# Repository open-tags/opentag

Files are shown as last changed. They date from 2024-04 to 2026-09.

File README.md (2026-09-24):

# opentag · early UWB prototype

Hardware, firmware, and an iOS app from the early opentags research project.

> **Historical R&D reference.** This prototype predates opentag U1 and uses different hardware and firmware. For current products and setup guides, visit [opentags](https://open-tags.com/) and the [documentation](https://open-tags.com/docs/).

[Hardware](Hardware/) · [Firmware](Firmware/README.md) · [iOS app](iOS/OpenTags/README.md) · [Current ROS 2 source](https://github.com/open-tags/open-tags.github.io/tree/main/ros2)

<p align="center">
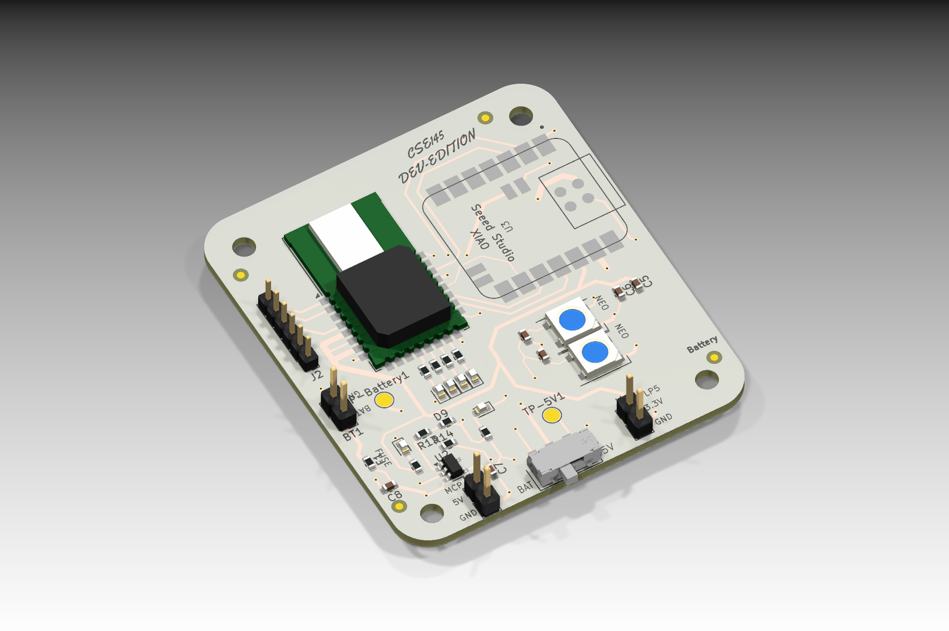
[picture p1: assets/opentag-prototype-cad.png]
KiCad 3D render of the historical opentag circuit board, showing its routing, mounting holes, connectors, and assigned component models
  
  <br>
  <sub>Historical prototype PCB · rendered directly from the KiCad board and its assigned 3D models</sub>
</p>

Some components have no assigned 3D model and appear as bare footprints. [Render details](assets/README.md)

<p align="center">
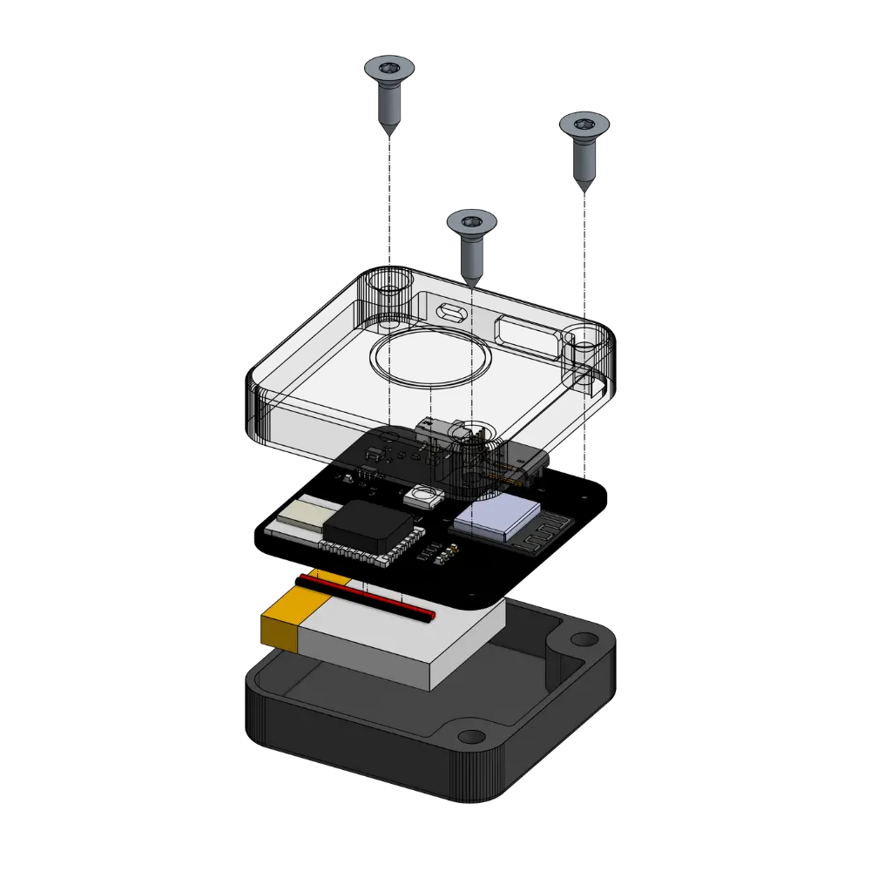
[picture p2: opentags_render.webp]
Original exploded CAD view of the early opentag prototype, showing its enclosure, circuit board, battery, and screws
  
  <br>
  <sub>Original prototype · exploded CAD view</sub>
</p>

## Explore the prototype

The project explored ultra-wideband (UWB) ranging and iPhone interaction. These files preserve that development work; they are not a complete, validated product release.

| Resource | What is included | Start here |
| --- | --- | --- |
| Hardware | KiCad schematics and board layouts, component libraries, BOMs, and fabrication exports | [KiCad project](Hardware/Hardware.kicad_pro) |
| Firmware | Arduino / PlatformIO experiments and bundled radio libraries | [Build notes and missing dependencies](Firmware/README.md) |
| iOS | Xcode project based on Apple's Nearby Interaction accessory sample | [iOS setup notes](iOS/OpenTags/README.md) |

## Before building

- **Firmware dependencies are incomplete.** The active PlatformIO target is `xiaoble_adafruit_nrf52`. The source includes `niq.h` and the configuration references NIQ libraries that are not included in this repository. A clean checkout is not ready to build; see the [firmware notes](Firmware/README.md).
- **The iOS app is experimental.** Its setup notes require an iPhone with Apple's U1 chip and a compatible accessory. Apple's U1 chip is unrelated to the opentag U1 product name.
- **Hardware files record prototype revisions.** Check the schematic, board revision, and firmware pin assignments together before fabrication or flashing.

## Current opentags resources

opentags now builds tracking hardware and integration tools for robotics. Start with the [website](https://open-tags.com/) for current products, the [documentation](https://open-tags.com/docs/) for setup, or the [ROS 2 source](https://github.com/open-tags/open-tags.github.io/tree/main/ros2) for robot integration.

This repository's prototype files and license do not describe the hardware, firmware, or licensing of current products.

## Questions and corrections

Use [Issues](https://github.com/open-tags/opentag/issues) for questions or corrections about this prototype. Include the board revision, toolchain, and relevant logs when reporting a build problem. For current product inquiries, contact [hello@open-tags.com](mailto:hello@open-tags.com).

## License

See the repository's [MIT license](LICENSE). Bundled third-party components retain their own license notices, including the [iOS sample](iOS/OpenTags/LICENSE/LICENSE.txt) and [Adafruit nRFCrypto](Firmware/lib/Adafruit_nRFCrypto/LICENSE).

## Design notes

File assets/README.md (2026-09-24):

# README render

`opentag-prototype-cad.png` was ray-traced with KiCad CLI 10.0.1 from
[`Hardware/Hardware.kicad_pcb`](../Hardware/Hardware.kicad_pcb). No generative AI
was used for this image.

The render preserves the board geometry, copper, silkscreen, component placements,
and assigned model transforms. Model paths were resolved in a temporary copy:
`${KIPRJMOD}` points to the original Hardware directory, and legacy KiCad 8 `.wrl`
references use the same-named `.step` models in the installed KiCad 10 library.
The source board and schematic were not modified.

Render settings: 1800 × 1200 pixels, top view, rotation `325,0,30`, zoom `0.72`,
high quality, opaque background, and floor shadows; board stackup colors retained.

This is a visualization of the saved CAD state, not a complete assembly model.
The Seeed Studio XIAO footprint has no assigned model. The radio footprint uses
the board's existing DWM1000 model assignment, despite its DWM3000 electrical
labels. These historical modeling limitations are preserved rather than filled
in with invented geometry.

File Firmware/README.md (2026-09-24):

# Prototype firmware

Arduino / PlatformIO experiments for the early opentag hardware. For current opentag U1 setup, use the [current documentation](https://open-tags.com/docs/).

## Build status

**A clean checkout is missing dependencies required by the firmware.**

The active environment in [platformio.ini](platformio.ini) is `xiaoble_adafruit_nrf52`, using the `xiaoble_adafruit` board and a custom Nordic nRF52 platform. The older `esp32-c3-devkitm-1` configuration is commented out and is not an active build target.

The checkout has these known dependency gaps:

- [src/main.cpp](src/main.cpp) includes `niq.h`, but that header is not present.
- The configuration searches `lib/niq/Inc` and links `niq-m4-hfp-1.1.0.0` and `niq-m4-sfp-1.1.0.0`. Those NIQ files are not tracked; `lib/niq` is excluded by the existing [.gitignore](.gitignore).
- Several configured include paths under `src/Comm`, `src/Helpers`, `src/AppConfig`, and `src/fira`, plus `lib/HAL/Inc`, are also absent.

Recover the matching dependencies and confirm their license terms before attempting a build. The custom platform URL is not pinned to a revision, so the configuration also does not capture a reproducible historical toolchain. Resolving the missing files alone does not establish a working build.

## Build after restoring dependencies

Install [PlatformIO Core](https://docs.platformio.org/page/core.html), then run from this repository's root:

```sh
cd Firmware
pio run -e xiaoble_adafruit_nrf52
```

This command selects the environment currently defined in the project; it is not a verified successful build. Confirm the board revision and pin assignments before uploading firmware to hardware.

To remove local build output:

```sh
pio run --target clean
```

[Back to the prototype overview](../README.md)

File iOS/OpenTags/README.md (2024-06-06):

# Implementing Spatial Interactions with Third-Party Accessories

Establish a connection with a nearby accessory to receive periodic measurements of its distance from the user.

## Overview

- Note: This sample code project is associated with WWDC21 session [10165: Explore Nearby Interaction with Third-Party Accessories](https://developer.apple.com/wwdc21/10165).

## Configure the Sample Code Project

Set the run destination to an iPhone that contains a U1 chip. The sample app interacts with an accessory you partner with or develop using the [Ultra Wideband (UWB) third-party device specification](https://developer.apple.com/nearby-interaction).

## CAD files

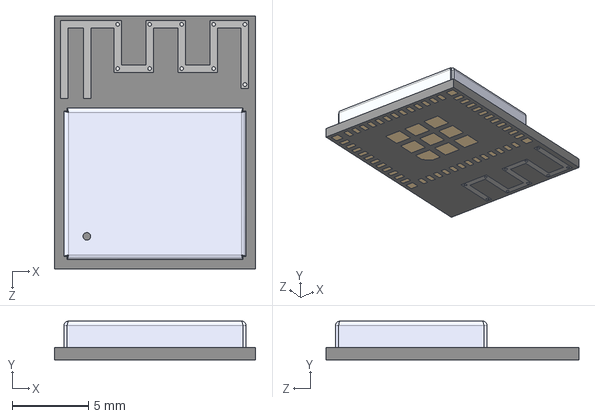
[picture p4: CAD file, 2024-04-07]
Hardware/ESP32-C3-MINI-1-N4/ESP32-C3-MINI-1-N4.step
13.2 x 2.55 x 16.6 mm

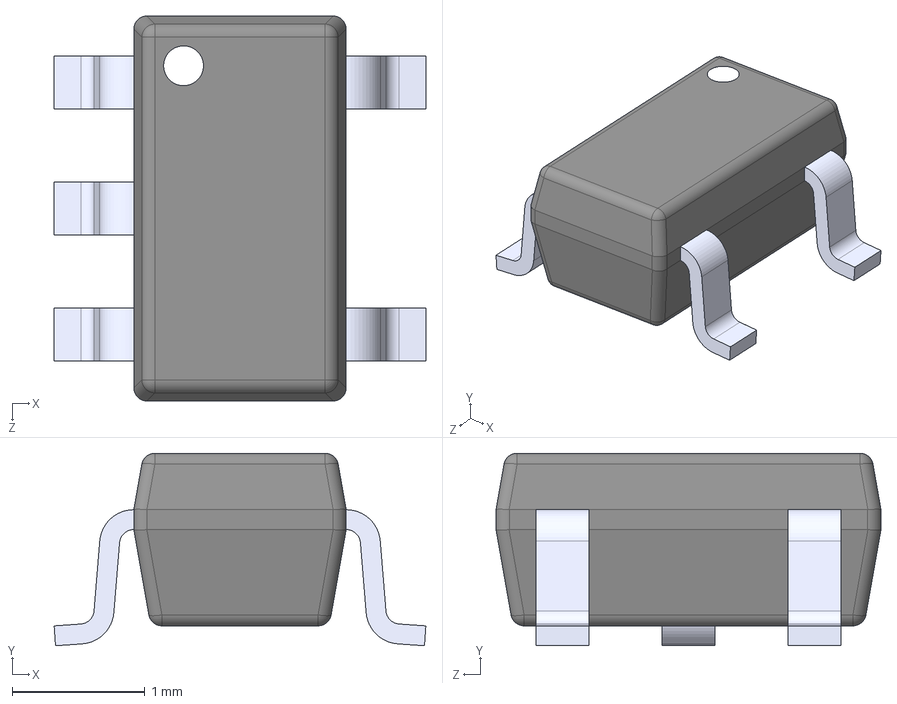
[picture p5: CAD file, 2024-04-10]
Hardware/LP5907MFX-3.3_NOPB/LP5907MFX-3.3_NOPB.step
2.80 x 1.45 x 2.90 mm

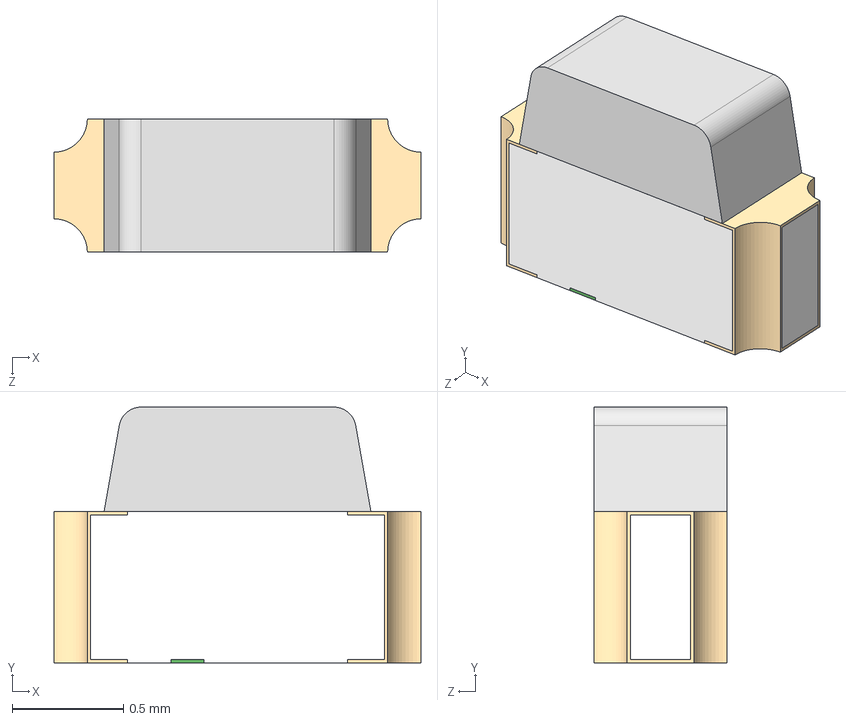
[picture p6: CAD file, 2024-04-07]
Hardware/LTST-S270KRKT/LTST-S270KRKT.step
1.65 x 1.15 x 0.6 mm

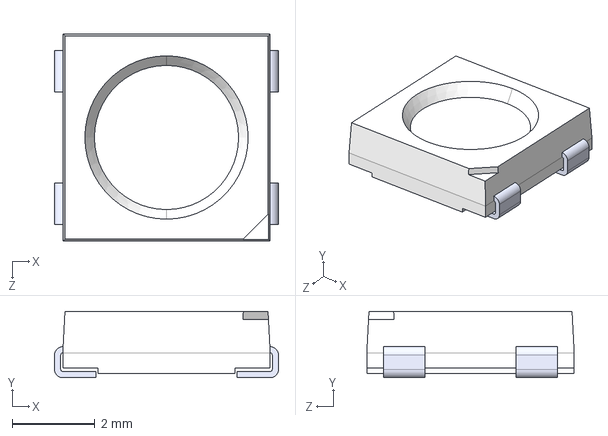
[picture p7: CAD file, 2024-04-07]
Hardware/NeoPixel/1655--3DModel-STEP-56544.STEP
5.40 x 1.60 x 5.00 mm

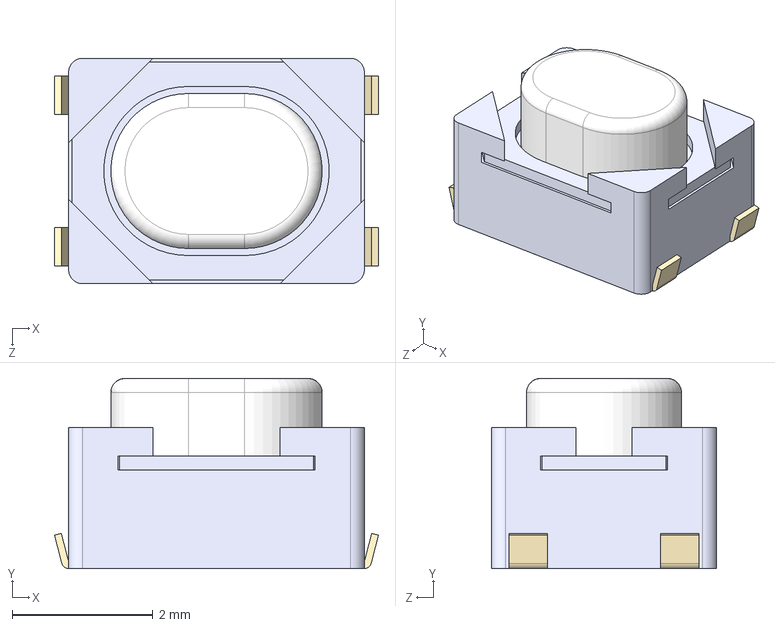
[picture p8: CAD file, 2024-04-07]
Hardware/PTS810 SJK 250 SMTR LFS--3DModel-STEP-56544.STEP
4.60 x 2.70 x 3.20 mm

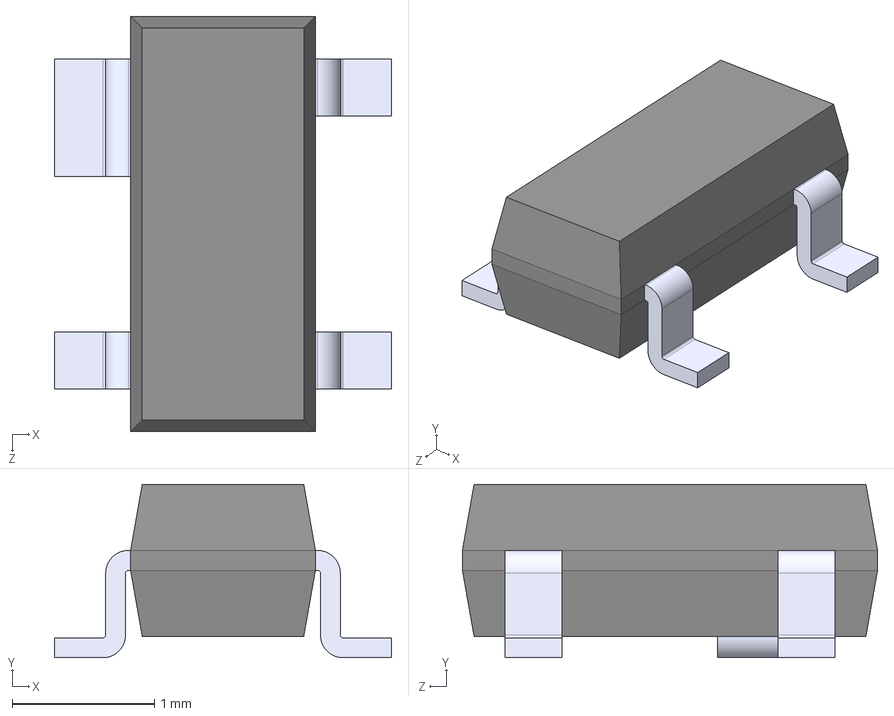
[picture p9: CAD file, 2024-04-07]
Hardware/SP0503BAHTG/SP0503BAHTG.step
2.37 x 1.22 x 2.92 mm

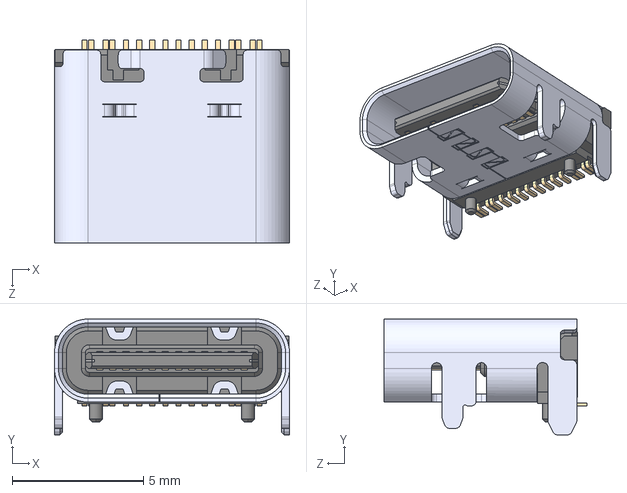
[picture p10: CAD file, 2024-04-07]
Hardware/USB4105-GF-A/USB4105-GF-A.step
8.94 x 4.41 x 7.71 mm

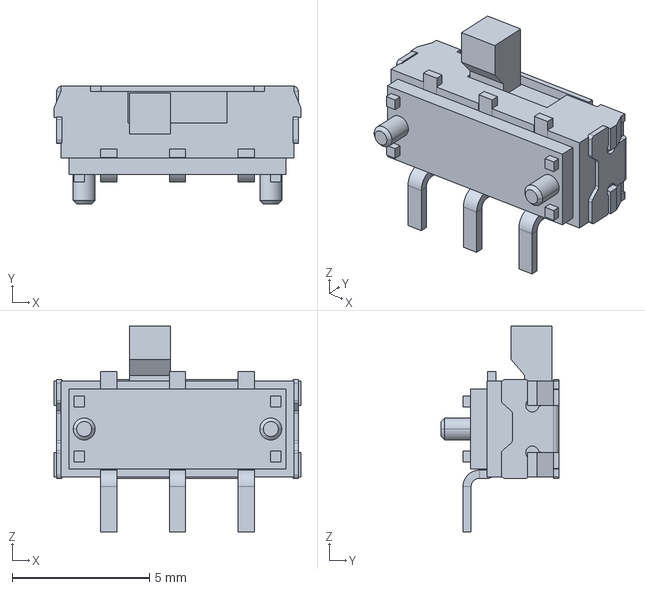
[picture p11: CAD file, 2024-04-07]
Hardware/JS102011SAQN/JS102011SAQN.step
9.00 x 4.30 x 7.50 mm

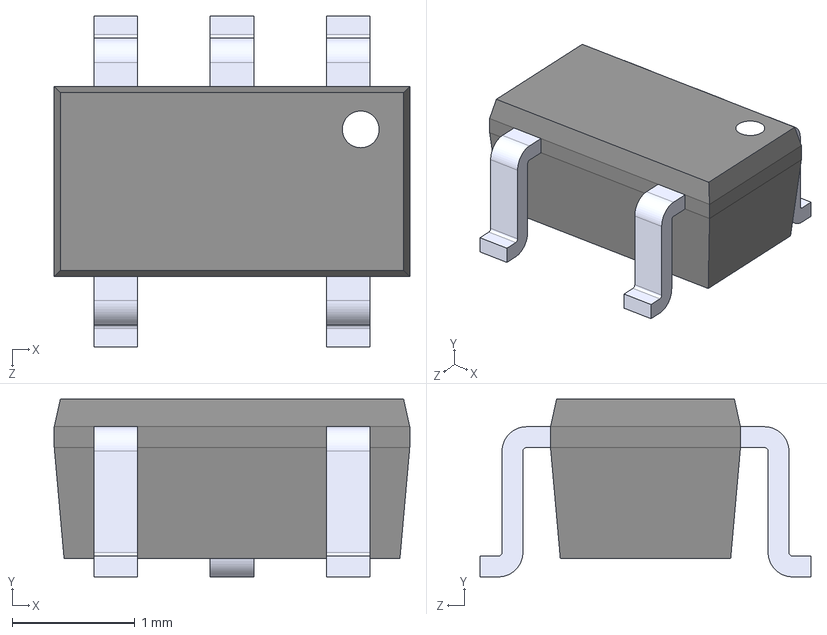
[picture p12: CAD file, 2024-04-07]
Hardware/MCP73831T-5ACI_OT/MCP73831T-5ACI_OT.step
2.90 x 1.45 x 2.70 mm

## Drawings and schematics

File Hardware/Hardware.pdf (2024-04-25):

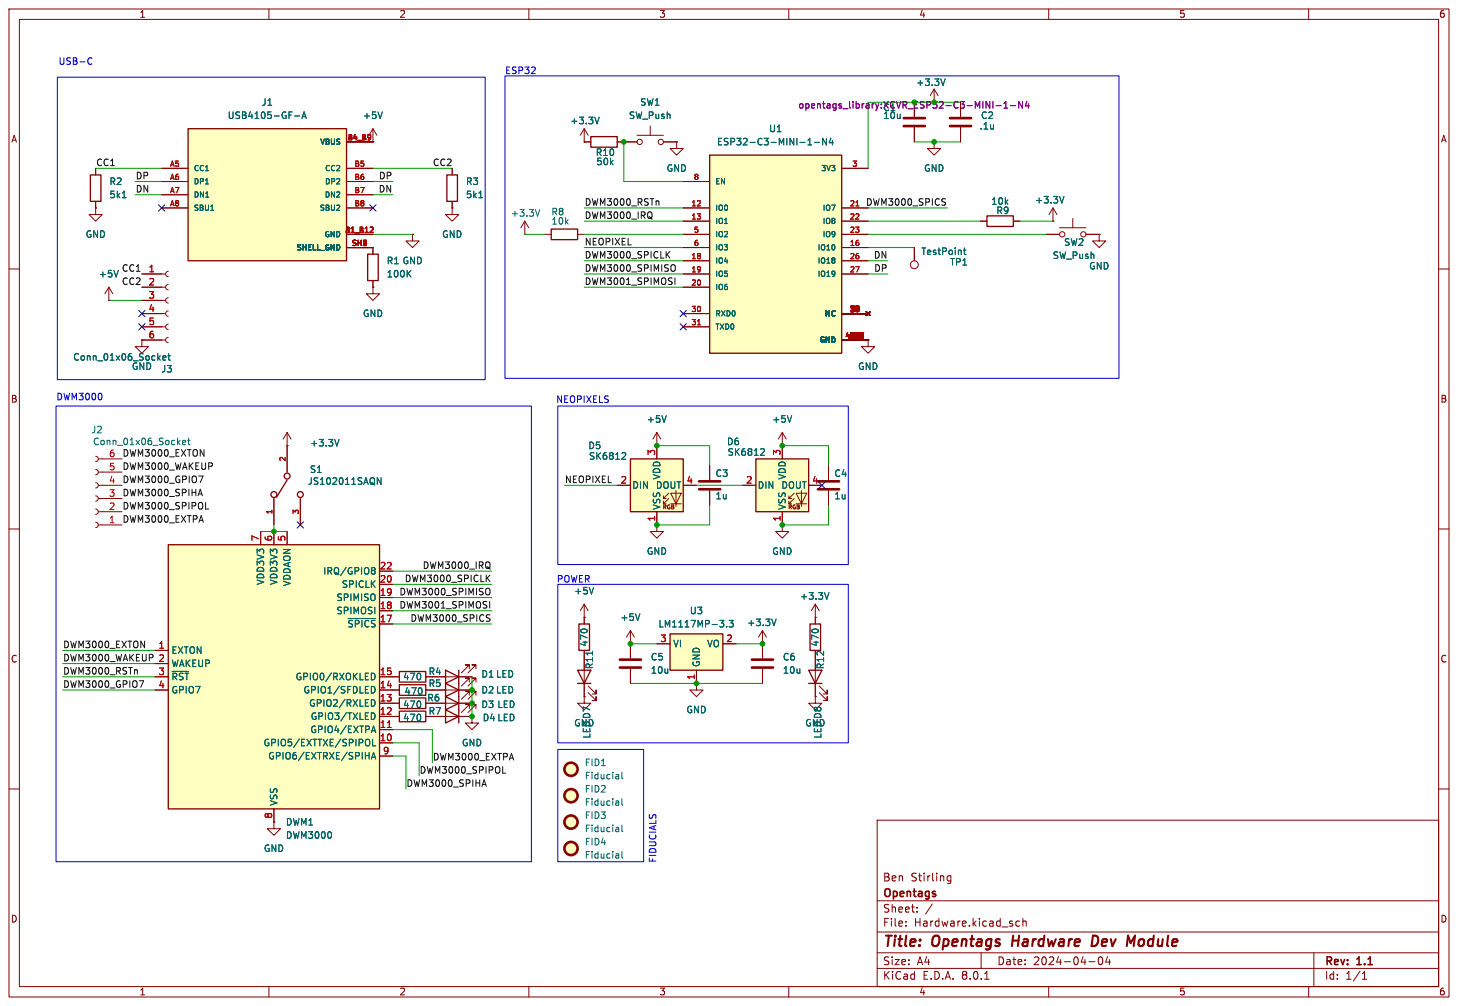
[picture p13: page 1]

File: Hardware.kicad_sch Sheet: / Opentags Ben Stirling

Id: 1/1 Title: Opentags Hardware Dev Module

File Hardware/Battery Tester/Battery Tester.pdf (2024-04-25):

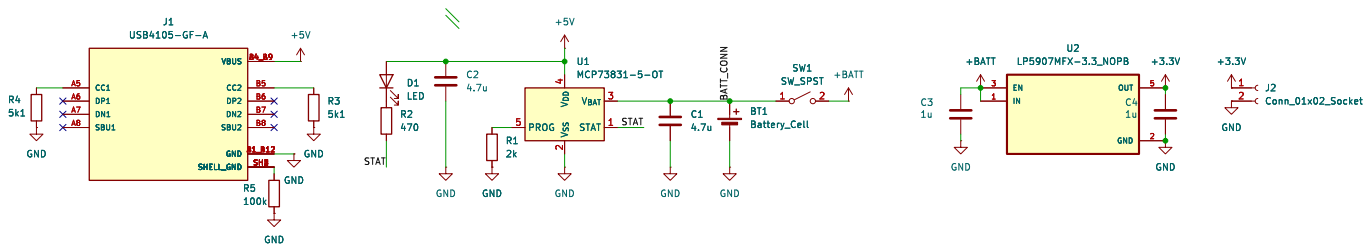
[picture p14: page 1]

Id: 1/1 Title: Battery Tester File: Battery Tester.kicad_sch Sheet: /

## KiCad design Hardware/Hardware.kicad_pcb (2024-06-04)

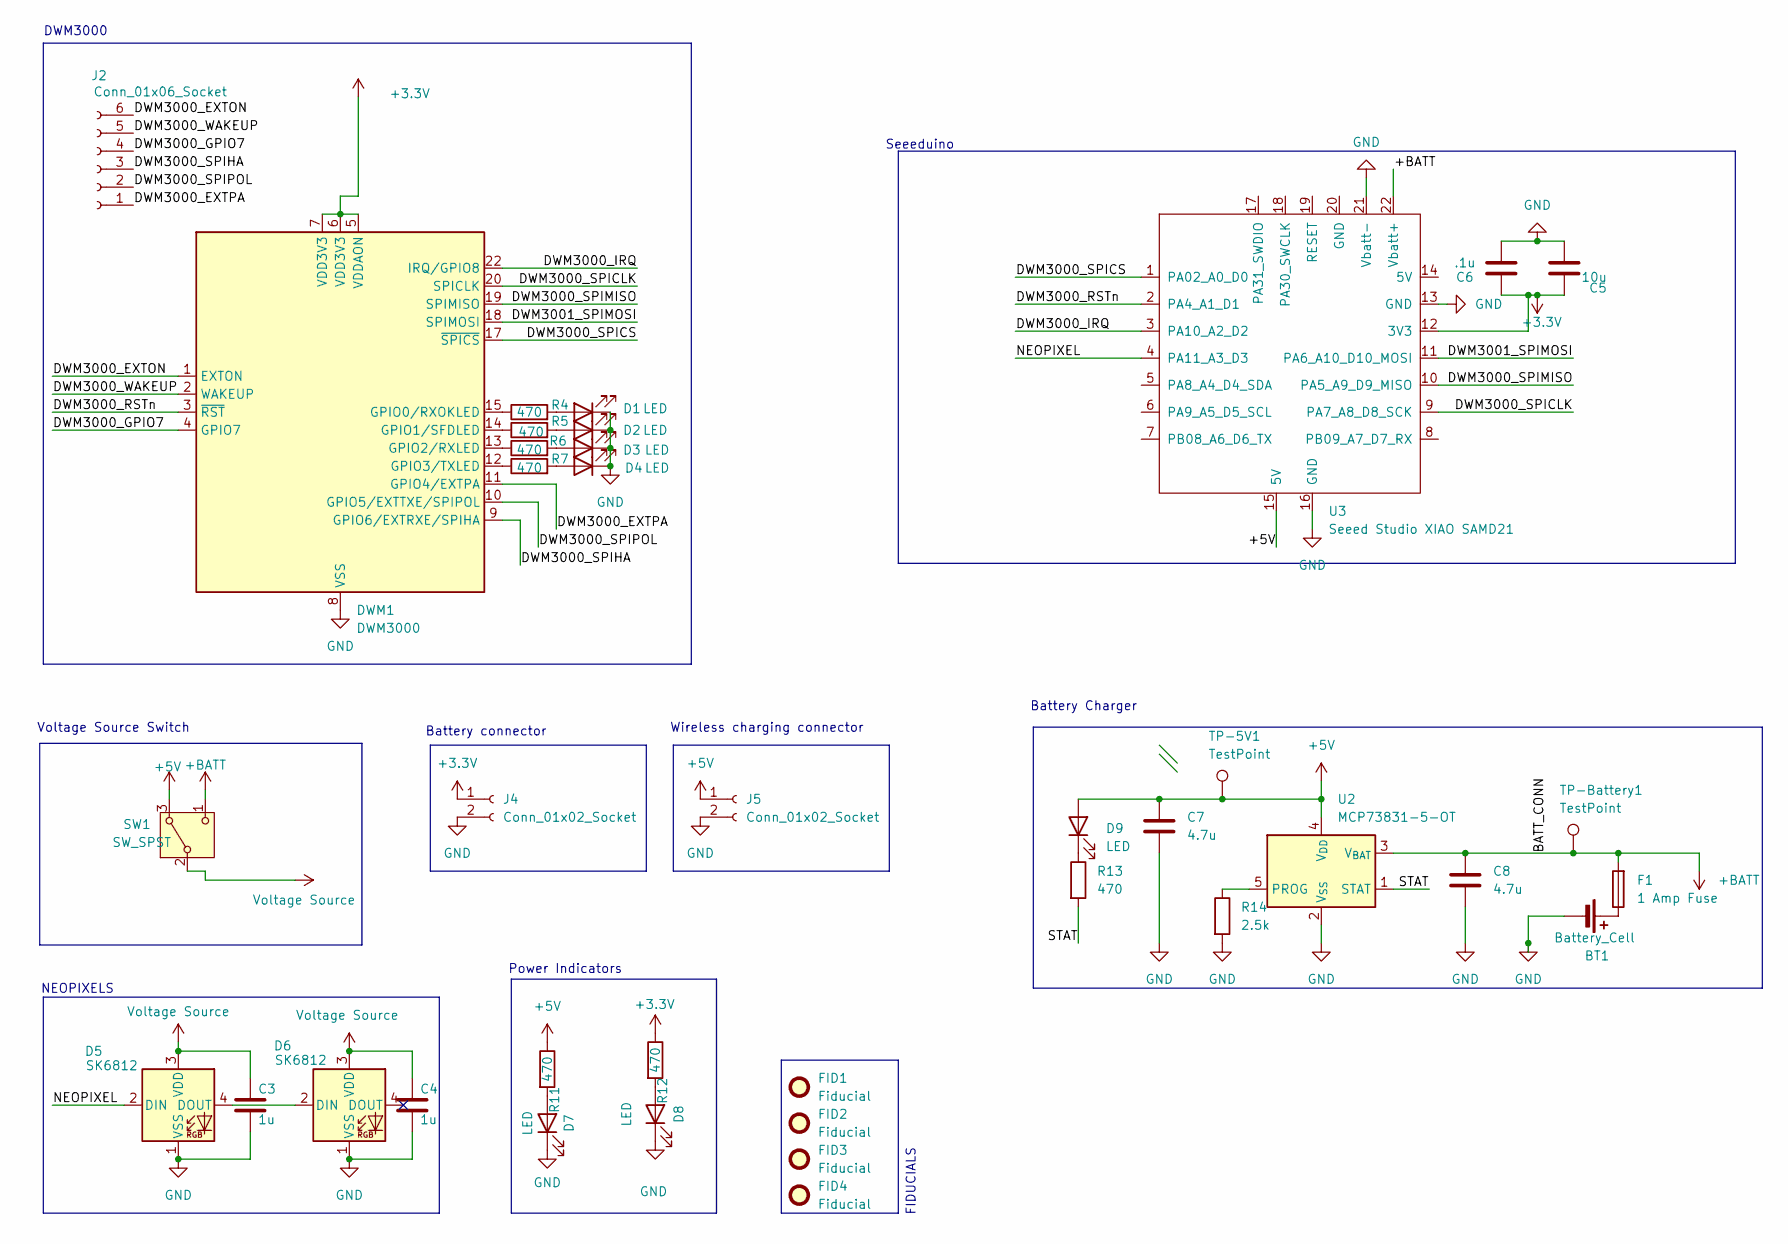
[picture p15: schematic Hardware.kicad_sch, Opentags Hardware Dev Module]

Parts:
BT1: Battery_Cell; PinHeader_1x02_P2.54mm_Vertical
C3, C4: 1u; C_0603_1608Metric
C5: 10u; C_0603_1608Metric
C6: .1u; C_0603_1608Metric
C7, C8: 4.7u; C_0603_1608Metric
D1, D2, D3, D4, D7, D8: LED; LED_0603_1608Metric
D5, D6: SK6812; LED_SK6812_PLCC4_5.0x5.0mm_P3.2mm
D9: LED; R_0603_1608Metric
DWM1: DWM3000; DWM1000
F1: 1 Amp Fuse; Fuse_0603_1608Metric
FID1, FID2, FID3, FID4: Fiducial; Fiducial_1mm_Mask2mm
J2: Conn_01x06_Socket; PinHeader_1x06_P2.00mm_Vertical
J4, J5: Conn_01x02_Socket; PinHeader_1x02_P2.54mm_Vertical
R4, R5, R6, R7, R11, R12, R13: 470; R_0603_1608Metric
R14: 2.5k; R_0603_1608Metric
SW1: SW_SPST; SW_JS102011SAQN
TP-5V1: TestPoint; TestPoint_Pad_D2.0mm
TP-Battery1: TestPoint; TestPoint_Pad_D2.0mm
U2: MCP73831-5-OT; SOT-23-5
U3: Seeed Studio XIAO SAMD21; XIAO-nRF52840-Sense-14P-2.54-21X17.8MM

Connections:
+3.3V: C5.1, C6.1, DWM1.5 (VDDAON), DWM1.6 (VDD3V3), DWM1.7 (VDD3V3), J4.1, R12.1, U3.12 (3V3)
+5V: C7.1, D9.2 (A), J5.1, R11.1, SW1.3 (A), TP-5V1.1, U2.4 (V_{DD}), U3.15 (5V)
+BATT: C8.1, F1.2, SW1.1 (C), TP-Battery1.1, U2.3 (V_{BAT}), U3.22 (Vbatt+)
/DWM3000_EXTON: DWM1.1 (EXTON), J2.6
/DWM3000_EXTPA: DWM1.11 (GPIO4/EXTPA), J2.1
/DWM3000_GPIO7: DWM1.4 (GPIO7), J2.4
/DWM3000_IRQ: DWM1.22 (IRQ/GPIO8), U3.3 (PA10_A2_D2)
/DWM3000_RSTn: DWM1.3 (~RST), U3.2 (PA4_A1_D1)
/DWM3000_SPICLK: DWM1.20 (SPICLK), U3.9 (PA7_A8_D8_SCK)
/DWM3000_SPICS: DWM1.17 (~SPICS), U3.1 (PA02_A0_D0)
/DWM3000_SPIHA: DWM1.9 (GPIO6/EXTRXE/SPIHA), J2.3
/DWM3000_SPIMISO: DWM1.19 (SPIMISO), U3.10 (PA5_A9_D9_MISO)
/DWM3000_SPIPOL: DWM1.10 (GPIO5/EXTTXE/SPIPOL), J2.2
/DWM3000_WAKEUP: DWM1.2 (WAKEUP), J2.5
/DWM3001_SPIMOSI: DWM1.18 (SPIMOSI), U3.11 (PA6_A10_D10_MOSI)
/NEOPIXEL: D5.2 (DIN), U3.4 (PA11_A3_D3)
/STAT: R13.2, U2.1 (STAT)
GND: BT1.2 (-), C3.1, C4.1, C5.2, C6.2, C7.2, C8.2, D1.1 (K), D2.1 (K), D3.1 (K), D4.1 (K), D5.1 (VSS), D6.1 (VSS), D7.1 (K), D8.1 (K), DWM1.8 (VSS), DWM1.16 (VSS), DWM1.21 (VSS), DWM1.23 (VSS), DWM1.24 (VSS), J4.2, J5.2, R14.2, U2.2 (V_{SS}), U3.13 (GND), U3.16 (GND), U3.21 (Vbatt-)
unnamed: BT1.1 (+), F1.1
unnamed: D1.2 (A), R4.2
unnamed: D2.2 (A), R5.2
unnamed: D3.2 (A), R6.2
unnamed: D4.2 (A), R7.2
unnamed: D5.4 (DOUT), D6.2 (DIN)
unnamed: D7.2 (A), R11.2
unnamed: D8.2 (A), R12.2
unnamed: D9.1 (K), R13.1
unnamed: DWM1.15 (GPIO0/RXOKLED), R4.1
unnamed: DWM1.14 (GPIO1/SFDLED), R5.1
unnamed: DWM1.13 (GPIO2/RXLED), R6.1
unnamed: DWM1.12 (GPIO3/TXLED), R7.1
unnamed: R14.1, U2.5 (PROG)
Voltage Source: C3.2, C4.2, D5.3 (VDD), D6.3 (VDD), SW1.2 (B)

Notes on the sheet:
Seeeduino
DWM3000
FIDUCIALS
Wireless charging connector
Battery Charger
NEOPIXELS
Power Indicators
Battery connector
Voltage Source Switch

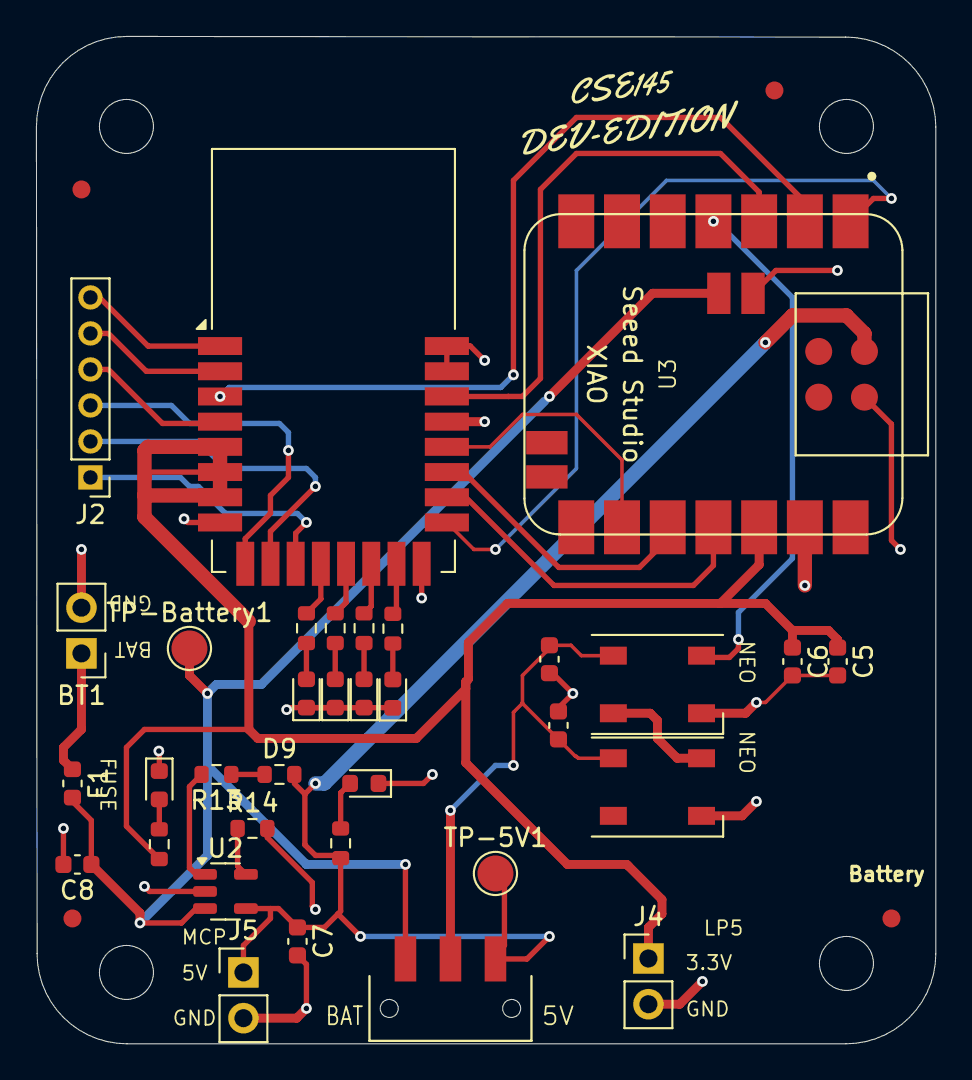
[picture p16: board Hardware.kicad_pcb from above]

Board: 2 copper layers, 50.0 x 56.0 mm, 38 parts (0 on the bottom side), 33 nets.

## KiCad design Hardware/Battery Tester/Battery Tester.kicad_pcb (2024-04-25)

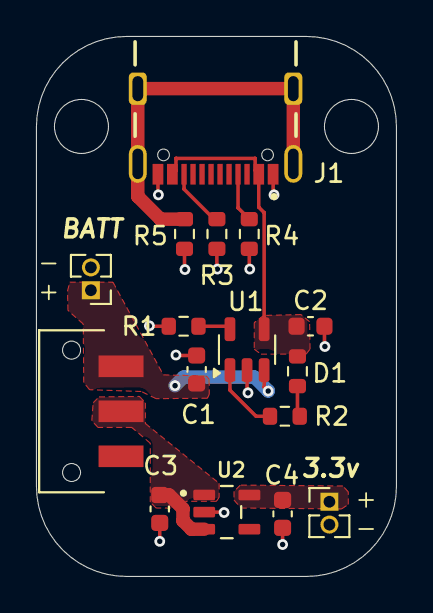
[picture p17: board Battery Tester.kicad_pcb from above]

Board: 2 copper layers, 20.0 x 30.0 mm, 16 parts (0 on the bottom side), 11 nets.

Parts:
3.3v: Conn_01x02_Socket; PinHeader_1x02_P1.27mm_Vertical
BATT: Battery_Cell; PinHeader_1x02_P1.27mm_Vertical
C1, C2: 4.7u; C_0603_1608Metric
C3, C4: 1u; C_0603_1608Metric
D1: LED; R_0603_1608Metric
J1: USB4105-GF-A; GCT_USB4105-GF-A
R1: 2k; R_0603_1608Metric
R2: 470; R_0603_1608Metric
R3, R4: 5k1; R_0603_1608Metric
R5: 100k; R_0603_1608Metric
SW1: SW_SPST; SW_JS102011SAQN
U1: MCP73831-5-OT; SOT-23-5
U2: LP5907MFX-3.3_NOPB; SOT95P280X145-5N

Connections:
+3.3V: 3.3v.1, C4.1, U2.5 (OUT)
+5V: C2.1, D1.2 (A), J1.A4_B9 (VBUS), J1.B4_A9 (VBUS), U1.4 (V_{DD})
+BATT: C3.1, SW1.2 (B), U2.1 (IN), U2.3 (EN)
/BATT_CONN: BATT.1 (+), C1.1, SW1.1 (A), U1.3 (V_{BAT})
/STAT: R2.2, U1.1 (STAT)
GND: 3.3v.2, BATT.2 (-), C1.2, C2.2, C3.2, C4.2, J1.A1_B12 (GND), J1.B1_A12 (GND), R1.2, R3.2, R4.2, R5.2, U1.2 (V_{SS}), U2.2 (GND)
unnamed: D1.1 (K), R2.1
unnamed: J1.A5 (CC1), R4.1
unnamed: J1.B5 (CC2), R3.1
unnamed: J1.SH1 (SHELL_GND), J1.SH2 (SHELL_GND), J1.SH3 (SHELL_GND), J1.SH4 (SHELL_GND), R5.1
unnamed: R1.1, U1.5 (PROG)

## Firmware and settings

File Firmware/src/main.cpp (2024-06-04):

#include "Arduino.h"
#include <stdio.h>
#include <dw3000.h>
extern "C" {
  #include <niq.h>
}

#include "Adafruit_nRFCrypto.h"
#include <BLEService.h>
#include <BLECharacteristic.h>
#include <bluefruit.h>


// Definitions 
#define APP_NAME "OPENTAG"
#define SPI_MOSI 10
#define SPI_MISO 9
#define SPI_SCK 8
#define SPI_CS 0
#define RST 1
#define IRQ 2

// BLE Service
BLEService myService("26b886e0-0bab-4d96-a8f3-f44fe442a700");
BLEService ANIService("48fe3e40-0817-4bb2-8633-3073689c2dba");

// BLE Characteristics
BLECharacteristic myTxChar("6E400002-B5A3-F393-E0A9-E50E24DCCA9E", BLEWrite | BLENotify | BLEIndicate, 38, true);
BLECharacteristic myRxChar("6E400003-B5A3-F393-E0A9-E50E24DCCA9E", BLERead);
BLECharacteristic ACD("95e8d9d5-d8ef-4721-9a4e-807375f53328", BLERead);

#define TX_ANT_DLY 16385
#define RX_ANT_DLY 16385

// DWM-3000 SPI commands
#define DWM3000_DEVID_REG 0x00

/* Frames used in the ranging process. See NOTE 3 below. */
static uint8_t tx_poll_msg[] = {0x41, 0x88, 0, 0xCA, 0xDE, 'W', 'A', 'V', 'E', 0xE0, 0, 0};
static uint8_t rx_resp_msg[] = {0x41, 0x88, 0, 0xCA, 0xDE, 'V', 'E', 'W', 'A', 0xE1, 0, 0, 0, 0, 0, 0, 0, 0, 0, 0};
/* Length of the common part of the message (up to and including the function code, see NOTE 3 below). */
#define ALL_MSG_COMMON_LEN 10
/* Indexes to access some of the fields in the frames defined above. */
#define ALL_MSG_SN_IDX 2
#define RESP_MSG_POLL_RX_TS_IDX 10
#define RESP_MSG_RESP_TX_TS_IDX 14
#define RESP_MSG_TS_LEN 4
/* Frame sequence number, incremented after each transmission. */
static uint8_t frame_seq_nb = 0;

/* Buffer to store received response message.
 * Its size is adjusted to longest frame that this example code is supposed to handle. */
#define RX_BUF_LEN 20
static uint8_t rx_buffer[RX_BUF_LEN];

/* Hold copy of status register state here for reference so that it can be examined at a debug breakpoint. */
static uint32_t status_reg = 0;
volatile static uint8_t start_uwb = 0;

/* Delay between frames, in UWB microseconds. See NOTE 1 below. */
#ifdef RPI_BUILD
#define POLL_TX_TO_RESP_RX_DLY_UUS 240
#endif //RPI_BUILD
#ifdef STM32F429xx
#define POLL_TX_TO_RESP_RX_DLY_UUS 240
#endif //STM32F429xx
#ifdef NRF52840_XXAA
#define POLL_TX_TO_RESP_RX_DLY_UUS 240
#endif //NRF52840_XXAA
/* Receive response timeout. See NOTE 5 below. */
#ifdef RPI_BUILD
#define RESP_RX_TIMEOUT_UUS 270
#endif //RPI_BUILD
#ifdef STM32F429xx
#define RESP_RX_TIMEOUT_UUS 210
#endif //STM32F429xx
#ifdef NRF52840_XXAA
#define RESP_RX_TIMEOUT_UUS 100
#endif //NRF52840_XXAA

#define POLL_TX_TO_RESP_RX_DLY_UUS 240
#define RESP_RX_TIMEOUT_UUS 0

dwt_config_t * dwt_config;

/* Hold copies of computed time of flight and distance here for reference so that it can be examined at a debug breakpoint. */
static double tof;
static double distance;

static uint8_t accessory_config_data_buffer[sizeof(struct AccessoryConfigurationData)];
static uint8_t accessory_config_data_length;

fira_device_configure_t fira_config;
extern dwt_txconfig_t txconfig_options;

static void send_accessory_config_data();

//**************************************************************************************************************
// BLE Related Methods
//*******************************************************************************************************

/**
 * Method to notify the client from the peripheral
*/
static void send_ble_data(uint8_t * buffer, uint16_t data_len){
  bool success = myTxChar.notify(buffer, data_len);
  if (success) {
    Serial.println("Data sent successfully");
  } else {
    Serial.println("Failed to send data");
  }
}

/**
 * Connect Callback for BLE
*/
static void send_ack_uwb_started(void)
{
      // Send "UWB did start" BLE message to the app
      uint8_t buffer[1] = {2};
      send_ble_data(buffer, 1);
}

void connect_callback(uint16_t conn_handle)
{
  Serial.print("【connect_callback】 conn_Handle : ");
  Serial.println(conn_handle, HEX);

  // Get the reference to current connection
  BLEConnection* connection = Bluefruit.Connection(conn_handle);

  Serial.println();
  // request PHY changed to 2MB (2Mbit/sec moduration) 1 --> 2
  Serial.print("Request to change PHY : "); Serial.print(connection->getPHY());
  connection->requestPHY();
  delayMicroseconds(1000000);  // delay a bit for all the request to complete
  Serial.print(" --> "); Serial.println(connection->getPHY());

  // request to update data length  27 --> 251
  Serial.print("Request to change Data Length : "); Serial.print(connection->getDataLength());
  connection->requestDataLengthUpdate();
  delayMicroseconds(1000000);  // delay a bit for all the request to complete
  Serial.print(" --> "); Serial.println(connection->getDataLength());
    
  // request mtu exchange 23 --> 247
  Serial.print("Request to change MTU : "); Serial.print(connection->getMtu());
  connection->requestMtuExchange(247);  // max 247
  //  connection->requestMtuExchange(123);  // max 247
  delayMicroseconds(1000000);  // delay a bit for all the request to complete
  Serial.print(" --> "); Serial.println(connection->getMtu());

  // request connection interval  16(20mS) --> 16(20mS)
  Serial.print("Request to change Interval : "); Serial.print(connection->getConnectionInterval());
  //  connection->requestConnectionParameter(16); // 20mS(in unit of 1.25) default 20mS
  delayMicroseconds(1000000);  // delay a bit for all the request to complete
  Serial.print(" --> "); Serial.println(connection->getConnectionInterval());

  char central_name[32] = { 0 };
  connection->getPeerName(central_name, sizeof(central_name));

  Serial.print("【connect_callback】 Connected to ");
  Serial.println(central_name);
}

/**
 * Disconnect Callback for BLE
*/
void disconnect_callback(uint16_t conn_handle, uint8_t reason)
{
  (void) conn_handle;
  (void) reason;

  Serial.print("【disconnect_callback】 reason = 0x");
  Serial.println(reason, HEX);
}

/**
 * Method to send the iPhone acknowledgement of 
 * receiving of Shared Configuration data
*/
static void send_ack_uwb_stopped(void)
{
    uint8_t buffer[1];
    ni_packet_t * packet = (ni_packet_t *)buffer;
    packet->message_id = (uint8_t)MessageId_accessoryUwbDidStop;
    send_ble_data(buffer, 1);
}

/**
 * This is the callback method passed onto the TX Characteristic 
*/
void onDataWritten(uint16_t conn_hdl, BLECharacteristic* chr, uint8_t* data, uint16_t len) {
  ni_packet_t * packet = (ni_packet_t *)data;
  switch (packet->message_id) {
    case MessageId_init: {
      send_accessory_config_data();
      break;
    }
    case MessageId_configure_and_start: {
      int ret;
      ret = niq_configure_and_start_uwb(packet->payload, len-1, (void*)&fira_config);

      switch(ret)
      {
      case -E_NIQ_INPVAL:
            Serial.println("ERROR: Data len wrong");
            break;
      case -E_NIQ_VERSIONNOTSUPPORTED:
            Serial.println("ERROR: Protocol version not supported");
            break;
      default:
        //Serial.println("UWB STARTED");
        send_ack_uwb_started();
        Serial.println("TWR Started");
        break;
      }

      break;
    }
    case MessageId_stop: {
      // Stop accessory UWB and reset state
      niq_stop_uwb();
      send_ack_uwb_stopped();
      break;
    }
    default: {
      Serial.println("Not Requesting Data");
      break;
    }
  }
}

//**************************************************************************************************************
// NIQ Middleware Related Methods
//*******************************************************************************************************

/*
 * @brief callback used for niq lib to signal session start
 */
void ResumeUwbTasks(void)
{ 
    start_uwb = 1;
}

/*
 * @brief callback used for niq lib to signal session stop
*/
void StopUwbTask(void)
{
    start_uwb = 0;
}

// Wrapper for nrf_crypto_init
void nrf_crypto_init_wrapper(void) {
    bool result = nRFCrypto.begin();
    if (!result) {
        Serial.println("Crypto init failed with error");
    }
}

// Wrapper for nrf_crypto_uninit
void nrf_crypto_uninit_wrapper(void) {
  nRFCrypto.end();
}

void nrf_crypto_rng_vector_generate_wrapper(uint8_t * const p_target, size_t size){
  bool result = nRFCrypto.Random.generate(p_target, size);
    if (!result) {
        Serial.println("Crypto generate failed with error");
    }
}


/**
 * Method to generate and send accesory config data
 * Designed as per structure defined in the
 * Nearby Interaction Accessory Protocol Specification - Release 2
*/
static void send_accessory_config_data() {
    niq_reinit();

    // The Accessory Configuration Data in intended to be constructed by the embedded application.

    // The message structure is the following:
    // ------------------------
    //     majorVersion         -- the major version from section 3.3 of the Nearby Interaction Accessory Protocol Specification, Developer Preview, Release 1.
    //     minorVersion         -- the minor version from section 3.3 of the Nearby Interaction Accessory Protocol Specification, Developer Preview, Release 1.
    //     preferredUpdateRate  -- a selection of one of the options from table 3-3 in the Nearby Interaction Accessory Protocol Specification, Developer Preview, Release 1.
    //     rfu[10]              -- reserved for future use.
    //     uwbConfigDataLength  -- the length of the UWB config data as provided by the UWB middleware.
    //     uwbConfigData        -- the UWB config data as provided by the UWB middleware, according to section 4.4.2 on the UWB Interoperability Specification, Developer Preview, Release 1.
    // ------------------------
    //
    // In order to populate `uwbConfigData` and `uwbConfigDataLength`, the embedded appliaction needs to query
    // the UWB middleware which is compliant with the UWB Interoperability Specification.
    //
    // Once the Accessory Configuration Data is constucted and populated, the embedded application needs to send it to the iOS app.

    uint8_t buffer[sizeof(struct AccessoryConfigurationData)+1]; // + 1 for the MessageId
    memset(buffer, 0, sizeof(struct AccessoryConfigurationData)+1);

    ni_packet_t * packet = (ni_packet_t *)buffer;
    packet->message_id = (uint8_t)MessageId_accessoryConfigurationData;

    // Embeded appliaction responsibility
    struct AccessoryConfigurationData *config = (struct AccessoryConfigurationData *)packet->payload;
    config->majorVersion = NI_ACCESSORY_PROTOCOL_SPEC_MAJOR_VERSION;
    config->minorVersion = NI_ACCESSORY_PROTOCOL_SPEC_MINOR_VERSION;
    config->preferredUpdateRate = PreferredUpdateRate_Automatic;
    
    // UWB middleware responsibility
    niq_populate_accessory_uwb_config_data(&config->uwbConfigData, &config->uwbConfigDataLength);

    send_ble_data(buffer, (uint16_t)(config->uwbConfigDataLength + ACCESSORY_CONFIGURATION_DATA_FIX_LEN + 1));
    memset(buffer, 0, sizeof(struct AccessoryConfigurationData)+1);
}

//**************************************************************************************************************
// Debug Methods
//*******************************************************************************************************

/**
 * Method to print out the buffer contents in binary
*/
void print_buffer_binary(uint8_t* buffer, size_t length) {
    for (size_t i = 0; i < length; ++i) {
        for (int8_t j = 7; j >= 0; --j) {
            Serial.print((buffer[i] >> j) & 1);
        }
        Serial.print(" ");
    }
    Serial.println();
}

/**
 * Method to print our value in binary
*/
void print_binary(uint32_t value) {
    char binary_str[33]; // 32 bits + null terminator
    binary_str[32] = '\0'; // Null terminator

    for (int i = 31; i >= 0; --i) {
        binary_str[i] = (value & 1) ? '1' : '0';
        value >>= 1;
    }

    Serial.println(binary_str);
}

/**
 * Method to debug an niq packet and its content
*/

void debug(ni_packet_t * packet){

    struct AccessoryConfigurationData *config = (struct AccessoryConfigurationData *)packet->payload;
    Serial.println((uint8_t)config->uwbConfigDataLength);

    Serial.println("Buffer in binary format (little-endian):");

    // Print the message ID
    Serial.println("Message ID");
    print_buffer_binary(&packet->message_id, 1);

    // Print the rest of the buffer in little-endian format
    Serial.println("Major Version");
    uint8_t* data_ptr = (uint8_t*)&config->majorVersion;
    for (int i = 0; i < sizeof(config->majorVersion); ++i) {
        print_buffer_binary(&data_ptr[i], 1);
    }

    Serial.println("Minor Version");
    data_ptr = (uint8_t*)&config->minorVersion;
    for (int i = 0; i < sizeof(config->minorVersion); ++i) {
        print_buffer_binary(&data_ptr[i], 1);
    }


    Serial.println("PUR");
    data_ptr = &config->preferredUpdateRate;
    print_buffer_binary(data_ptr, 1);

    for (int i = 0; i < sizeof(config->rfu); ++i) {
        print_buffer_binary(&config->rfu[i], 1);
    }

    Serial.println("uwbConfigDataLength");
    data_ptr = &config->uwbConfigDataLength;
    print_buffer_binary(data_ptr, 1);

    Serial.println("uwbConfigData");
    for (int i = 0; i < config->uwbConfigDataLength; ++i) {
        print_buffer_binary(&config->uwbConfigData[i], 1);
    }
}


//**************************************************************************************************************
// Setup and Looping
//*******************************************************************************************************

void spi_rd_err_cb(){
  Serial.print("SPI Read error Call Back");
}

void setup() {
  // Initialize serial communication
  Serial.begin(115200);
  while (!Serial) {
    ; // Wait for serial port to connect
  }

  // Initialize pins
  pinMode(SPI_MOSI, OUTPUT);
  pinMode(SPI_MISO, INPUT);
  pinMode(SPI_SCK, OUTPUT);
  pinMode(SPI_CS, OUTPUT);
  pinMode(IRQ, INPUT_PULLUP);
  attachInterrupt(digitalPinToInterrupt(IRQ), dwt_isr, RISING);
  spiBegin(IRQ, RST);
  spiSelect(SPI_CS);

  // Populate the dwt_config (Currently hardcoded)
  uint8_t sfd_id = 2;
  dwt_config->chan = 9;
  dwt_config->sfdType = (sfd_id == 0) ? DWT_SFD_IEEE_4A : DWT_SFD_IEEE_4Z; //TBD: maybe_flawed?
  //dwt_config->sfdType = 2;
  dwt_config->txCode = 11;
  dwt_config->rxCode = 11;
  dwt_config->txPreambLength = DWT_PLEN_64;
  dwt_config->rxPAC = DWT_PAC8;
  dwt_config->dataRate = DWT_BR_6M8;
  dwt_config->phrMode = DWT_PHRMODE_STD;
  dwt_config->phrRate = DWT_PHRRATE_STD;
  dwt_config->sfdTO = (65  + 8 - 8) ;
  dwt_config->stsMode = DWT_STS_MODE_OFF;
  dwt_config->stsLength = DWT_STS_LEN_64;
  dwt_config->pdoaMode = DWT_PDOA_M0;

  while (!dwt_checkidlerc()) // Need to make sure DW IC is in IDLE_RC before proceeding 
  {
    Serial.println("IDLE FAILED\r\n");
    while (1) ;
  }

  // Enab
  dwt_setleds(DWT_LEDS_ENABLE | DWT_LEDS_INIT_BLINK);

  if (dwt_initialise(DWT_DW_IDLE_RC) == DWT_ERROR)
  {
    Serial.println("INIT FAILED\r\n");
    while (1) ;
  }

    /* Configure DW IC. See NOTE 6 below. */
  if(dwt_configure(dwt_config)) // if the dwt_configure returns DWT_ERROR either the PLL or RX calibration has failed the host should reset the device
  {
    UART_puts("CONFIG FAILED\r\n");
    while (1) ;
  }

    /* Configure the TX spectrum parameters (power, PG delay and PG count) */
  dwt_configuretxrf(&txconfig_options);

  /* Apply default antenna delay value. See NOTE 2 below. */
  dwt_setrxantennadelay(RX_ANT_DLY);
  dwt_settxantennadelay(TX_ANT_DLY);

  dwt_enablespicrccheck(DWT_SPI_CRC_MODE_NO, spi_rd_err_cb);

  // TODO: Replace code after this to switch is with Tx/Rx
  // Don't change other shit pls
  dwt_setrxaftertxdelay(POLL_TX_TO_RESP_RX_DLY_UUS);
  dwt_setrxtimeout(RESP_RX_TIMEOUT_UUS);
  dwt_setlnapamode(DWT_LNA_ENABLE | DWT_PA_ENABLE);

  // Initialize UWB and Bluefruit
  niq_init(ResumeUwbTasks, StopUwbTask, nrf_crypto_init_wrapper, nrf_crypto_uninit_wrapper, nrf_crypto_rng_vector_generate_wrapper);
  niq_set_ranging_role(0);
 

  Bluefruit.configPrphBandwidth(BANDWIDTH_MAX);
  Bluefruit.begin(1,0);
  Bluefruit.setTxPower(4);    // Check bluefruit.h for supported values
  Bluefruit.Periph.setConnectCallback(connect_callback);
  Bluefruit.Periph.setDisconnectCallback(disconnect_callback);

  // Initialize the first service and characteristic
  myService.begin();
  myTxChar.setPermission(SECMODE_OPEN, SECMODE_OPEN);
  myTxChar.begin();
  myTxChar.setWriteCallback(onDataWritten);

  // // Prepare accessory data
  // niq_populate_accessory_uwb_config_data(accessory_config_data_buffer, &accessory_config_data_length);
  // accessory_config_data_length += ACCESSORY_CONFIGURATION_DATA_FIX_LEN;

  // // Initialize the second service and characteristic
  ANIService.begin();
  ACD.setPermission(SECMODE_OPEN, SECMODE_OPEN);
  ACD.setFixedLen(accessory_config_data_length);
  ACD.setBuffer(accessory_config_data_buffer, (uint16_t)accessory_config_data_length);
  ACD.begin();
  // ACD.setWriteCallback(onDataWritten);

  // Start advertising
  Bluefruit.Advertising.addFlags(BLE_GAP_ADV_FLAGS_LE_ONLY_GENERAL_DISC_MODE);
  Bluefruit.Advertising.addTxPower();
  Bluefruit.Advertising.addService(myService);
  Bluefruit.Advertising.addName();

  /* Start Advertising
   * - Enable auto advertising if disconnected
   * - Interval:  fast mode = 20 ms, slow mode = 152.5 ms
   * - Timeout for fast mode is 30 seconds
   * - Start(timeout) with timeout = 0 will advertise forever (until connected)
   */
  Bluefruit.Advertising.restartOnDisconnect(true);
  Bluefruit.Advertising.setInterval(32, 244);    // in unit of 0.625 ms
  Bluefruit.Advertising.setFastTimeout(30);      // number of seconds in fast mode
  Bluefruit.Advertising.start(0);                // 0 = Don't stop advertising after n seconds
  Serial.println("Awaiting for Connection");
}

void loop() {
  while (!start_uwb){}
  //start_TWR(); --> To be implemented
}

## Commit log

2024-03-19 Firmware init
    [Hardware.kicad_pcb, Hardware.kicad_sch]
2024-04-10 battery tester board
    [Battery Tester.kicad_pcb, Battery Tester.kicad_sch, LP5907MFX-3.3_NOPB.step]
2024-04-16 Adding PDFs for the schematics
    [Battery Tester.kicad_pcb, Battery Tester.kicad_sch]
2024-04-30 Initial commit of new feature/battery
    [Battery Tester-B_Cu.gbr, Battery Tester-B_Mask.gbr, Battery Tester-B_Paste.gbr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]
2024-05-21 Switched to nrF
2024-06-04 hardware updates
    [Battery Tester-B_Cu.gbr, Battery Tester-B_Mask.gbr, Battery Tester-B_Paste.gbr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]
2026-09-24 Refresh the legacy README with a KiCad render and accurate build notes (#9)
    * Clarify legacy prototype documentation and remove Finder metadata
    * Add studio render of the historical opentag prototype
    * Revert "Add studio render of the historical opentag prototype"
    This reverts commit 68c0cee772df282f5d306e7f762ca75f58ffe86a.
    * Render README image directly from the KiCad board
    * Remove links to the original exploded illustration
    * Show the original exploded render in the README
